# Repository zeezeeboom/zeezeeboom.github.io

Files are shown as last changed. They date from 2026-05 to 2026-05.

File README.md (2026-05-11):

# 3D Print Files

STL files for the enclosure, panel, brackets, knobs, and mounts.

## First Draft Warning

The current 3D model is a first draft. The original build required cutting and sawing parts of the print to make everything fit. Expect to trim, sand, drill, or adjust the printed parts before final assembly.

Included files:

- `AV_joystick.zip` - contains `AV_joystick.stl`; zipped because the raw STL is too large for GitHub browser upload
- `base (2).stl`
- `bottom.stl`
- `F1_knobs.stl`
- `Faceplate Riser.stl`
- `faceplate.stl`

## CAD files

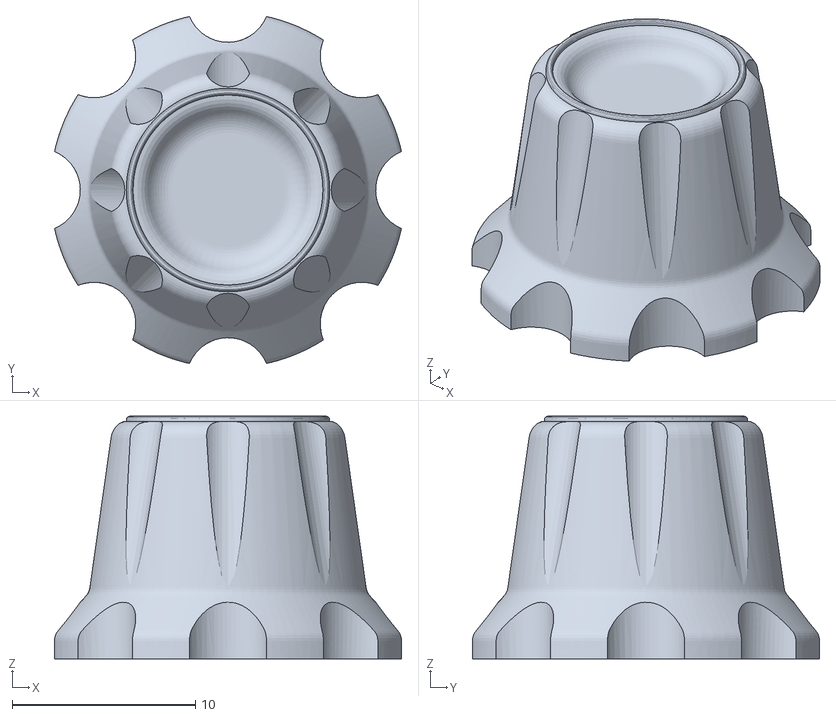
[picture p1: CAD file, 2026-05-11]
F1_knobs.stl
18.9 x 18.9 x 13.2

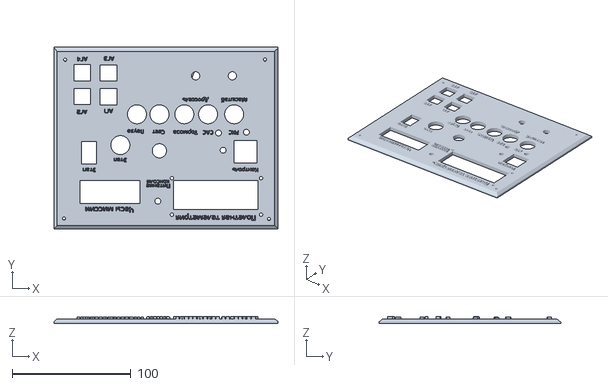
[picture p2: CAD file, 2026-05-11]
faceplate.stl
189.0 x 153.9 x 6.14

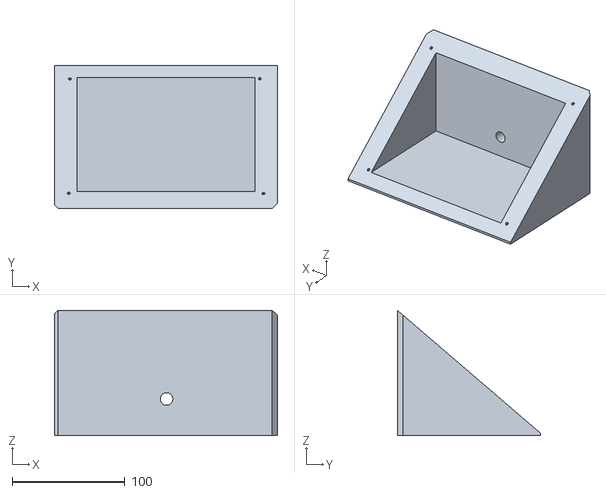
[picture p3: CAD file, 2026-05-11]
base (2).stl
198.1 x 127.2 x 111.3

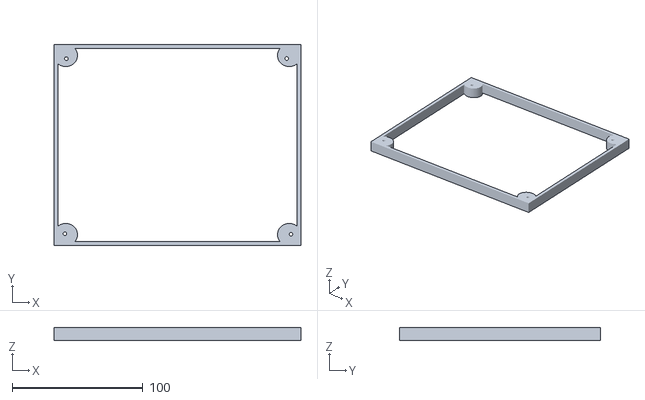
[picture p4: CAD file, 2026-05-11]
Faceplate Riser.stl
189.0 x 154.0 x 10.0

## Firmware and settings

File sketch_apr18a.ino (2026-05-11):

#include <Wire.h>
#include <LiquidCrystal_I2C.h>
#include <KerbalSimpit.h>
#include <Encoder.h>
#include <SevSeg.h>

KerbalSimpit mySimpit(Serial);
LiquidCrystal_I2C lcd(0x27, 16, 2);
SevSeg sevseg;

// Joystick
const byte PIN_VERTICAL = A0;
const byte PIN_HORIZONTAL = A1;
const byte PIN_JOYSTICK_SW = 46;

// LCD page encoder
Encoder pageEnc(2, 3);
const byte PIN_PAGE_ENC_SW = 4;

// One shared toggle switch
const byte PIN_DISPLAY_MODE_SWITCH = 5;

// LEDs
const byte PIN_SAS_LED = 6;
const byte PIN_RCS_LED = 7;
const byte PIN_ORBIT_LED = 15;
const byte PIN_SYSTEM_OFF_LED = 16;

// Main controls
const byte PIN_BRAKES = 8;
const byte PIN_LIGHTS = 9;
const byte PIN_STAGE = 10;
const byte PIN_SAS = 11;
const byte PIN_RCS = 12;
const byte PIN_GEAR = 14;

// Throttle encoder
Encoder throttleEnc(18, 19);
const byte PIN_THROTTLE_SW = 29;

// 1 digit stage display: A, B, C, D, E, F, G
const byte stageSegmentPins[] = {22, 23, 24, 25, 26, 27, 28};

// 4 digit 7 segment altitude display
byte numDigits = 4;

// Reversed from original so USSR displays in the correct order
byte digitPins[] = {30, 31, 32, 33};

byte segmentPins[] = {34, 35, 36, 37, 38, 39, 40, 41};

// Action groups
const byte agPins[] = {42, 43, 44, 45};

const int DEADZONE = 50;
const unsigned long BUTTON_DEBOUNCE_MS = 250;
const unsigned long JOYSTICK_SEND_MS = 20;
const unsigned long LCD_UPDATE_MS = 100;
const unsigned long SEV_SET_MS = 25;

const uint16_t MAX_THROTTLE = 65535;
const uint16_t MIN_THROTTLE = 0;
const uint16_t STEP_SIZE = 2184;
const long MAX_ENCODER_POS = 120;

const int totalPages = 4;

const byte digitPatterns[] = {
  0b00111111,
  0b00000110,
  0b01011011,
  0b01001111,
  0b01100110,
  0b01101101,
  0b01111101,
  0b00000111,
  0b01111111,
  0b01101111
};

// Stage countdown / display
bool isCounting = false;
bool firstStageDone = false;
int stageCount = 0;
unsigned long stageStartTime = 0;

// LCD pages
long oldPagePosition = -999;
int currentPage = 0;

// Throttle
uint16_t currentThrottle = 0;
long oldThrottlePosition = -999;

// Flight data
double vSurf = 0.0;
float altSea = 0.0;
float apoapsis = 0.0;
float periapsis = 0.0;
float burnDV = 0.0;
int32_t burnTime = 0;
float targetDist = 0.0;
float targetV = 0.0;

// 4 digit display data
long currentAltitude = 0;
bool connected = false;

// LEDs
bool reachedSpace = false;

// Timing state for stable SevSeg refresh
unsigned long lastJoystickSend = 0;
unsigned long lastJoystickToggle = 0;
unsigned long lastLcdUpdate = 0;
unsigned long lastSevSet = 0;

// Button states
bool lastAgState[4] = {HIGH, HIGH, HIGH, HIGH};
bool lastStageState = HIGH;
bool lastPageEncSwState = HIGH;
bool lastJoystickSwState = HIGH;
bool joystickRollMode = false;
bool lastSasState = HIGH;
bool lastRcsState = HIGH;
bool lastBrakesState = HIGH;
bool lastLightsState = HIGH;
bool lastGearState = HIGH;
bool lastThrottleSwState = HIGH;

bool pressed(byte pin, bool &lastState) {
  bool currentState = digitalRead(pin);
  bool didPress = currentState == LOW && lastState == HIGH;
  lastState = currentState;
  return didPress;
}

bool displayModeActive() {
  return digitalRead(PIN_DISPLAY_MODE_SWITCH) == LOW;
}

void displayStageDigit(int digit) {
  if (digit < 0 || digit > 9) {
    for (int i = 0; i < 7; i++) {
      digitalWrite(stageSegmentPins[i], LOW);
    }
    return;
  }

  byte pattern = digitPatterns[digit];

  for (int i = 0; i < 7; i++) {
    digitalWrite(stageSegmentPins[i], bitRead(pattern, i));
  }
}

void resetStageDisplay() {
  isCounting = false;
  firstStageDone = false;
  stageCount = 0;
  displayStageDigit(-1);
}

void formatDist(float dist) {
  if (dist > 1000000) {
    lcd.print(dist / 1000000, 2);
    lcd.print("Mm");
  } else if (dist > 10000) {
    lcd.print(dist / 1000, 1);
    lcd.print("km");
  } else {
    lcd.print(dist, 0);
    lcd.print("m");
  }
}

void displayAscent() {
  sevseg.refreshDisplay();
  lcd.setCursor(0, 0);
  lcd.print("SPD:");
  lcd.print(vSurf, 1);
  lcd.print("m/s    ");

  sevseg.refreshDisplay();
  lcd.setCursor(0, 1);
  lcd.print("ALT:");
  lcd.print(altSea > 10000 ? altSea / 1000 : altSea, 1);
  lcd.print(altSea > 10000 ? "km     " : "m      ");
  sevseg.refreshDisplay();
}

void displayOrbit() {
  sevseg.refreshDisplay();
  lcd.setCursor(0, 0);
  lcd.print("AP:");
  formatDist(apoapsis);
  lcd.print("        ");

  sevseg.refreshDisplay();
  lcd.setCursor(0, 1);
  lcd.print("PE:");
  formatDist(periapsis);
  lcd.print("        ");
  sevseg.refreshDisplay();
}

void displayManeuver() {
  sevseg.refreshDisplay();
  lcd.setCursor(0, 0);
  lcd.print("NODE:");
  lcd.print(burnDV, 1);
  lcd.print("dV     ");

  sevseg.refreshDisplay();
  lcd.setCursor(0, 1);
  lcd.print("TIME:");
  lcd.print(burnTime);
  lcd.print("s      ");
  sevseg.refreshDisplay();
}

void displayTarget() {
  sevseg.refreshDisplay();
  lcd.setCursor(0, 0);
  lcd.print("TGT:");
  formatDist(targetDist);
  lcd.print("        ");

  sevseg.refreshDisplay();
  lcd.setCursor(0, 1);
  lcd.print("RELV:");
  lcd.print(targetV, 1);
  lcd.print("m/s    ");
  sevseg.refreshDisplay();
}

void messageHandler(byte messageType, byte msg[], byte msgSize) {
  switch (messageType) {
    case VELOCITY_MESSAGE:
      if (msgSize == sizeof(velocityMessage)) {
        velocityMessage vData;
        memcpy(&vData, msg, sizeof(velocityMessage));
        vSurf = vData.surface;
      }
      break;

    case ALTITUDE_MESSAGE:
      if (msgSize == sizeof(altitudeMessage)) {
        altitudeMessage aData;
        memcpy(&aData, msg, sizeof(altitudeMessage));

        altSea = aData.sealevel;
        currentAltitude = (long)aData.sealevel;
        connected = true;

        if (altSea >= 70000.0) {
          reachedSpace = true;
        }

        if (altSea < 500.0) {
          reachedSpace = false;
        }

        digitalWrite(PIN_ORBIT_LED, reachedSpace ? HIGH : LOW);
      }
      break;

    case APSIDES_MESSAGE:
      if (msgSize == sizeof(apsidesMessage)) {
        apsidesMessage apData;
        memcpy(&apData, msg, sizeof(apsidesMessage));
        apoapsis = apData.apoapsis;
        periapsis = apData.periapsis;
      }
      break;

    case MANEUVER_MESSAGE:
      if (msgSize == sizeof(maneuverMessage)) {
        maneuverMessage mData;
        memcpy(&mData, msg, sizeof(maneuverMessage));
        burnDV = mData.deltaVTotal;
        burnTime = mData.timeToNextManeuver;
      }
      break;

    case TARGETINFO_MESSAGE:
      if (msgSize == sizeof(targetMessage)) {
        targetMessage tData;
        memcpy(&tData, msg, sizeof(targetMessage));
        targetDist = tData.distance;
        targetV = tData.velocity;
      }
      break;

    case ACTIONSTATUS_MESSAGE:
      {
        bool sasActive = msg[0] & 16;
        bool rcsActive = msg[0] & 8;

        digitalWrite(PIN_SAS_LED, sasActive ? HIGH : LOW);
        digitalWrite(PIN_RCS_LED, rcsActive ? HIGH : LOW);
        digitalWrite(PIN_SYSTEM_OFF_LED, (!sasActive && !rcsActive) ? HIGH : LOW);
      }
      break;
  }
}

void setup() {
  Serial.begin(115200);

  pinMode(PIN_VERTICAL, INPUT);
  pinMode(PIN_HORIZONTAL, INPUT);
  pinMode(PIN_JOYSTICK_SW, INPUT_PULLUP);

  pinMode(PIN_PAGE_ENC_SW, INPUT_PULLUP);
  pinMode(PIN_DISPLAY_MODE_SWITCH, INPUT_PULLUP);

  pinMode(PIN_STAGE, INPUT_PULLUP);
  pinMode(PIN_SAS, INPUT_PULLUP);
  pinMode(PIN_RCS, INPUT_PULLUP);
  pinMode(PIN_BRAKES, INPUT_PULLUP);
  pinMode(PIN_LIGHTS, INPUT_PULLUP);
  pinMode(PIN_GEAR, INPUT_PULLUP);
  pinMode(PIN_THROTTLE_SW, INPUT_PULLUP);

  for (int i = 0; i < 4; i++) {
    pinMode(agPins[i], INPUT_PULLUP);
  }

  for (int i = 0; i < 7; i++) {
    pinMode(stageSegmentPins[i], OUTPUT);
  }

  pinMode(PIN_SAS_LED, OUTPUT);
  pinMode(PIN_RCS_LED, OUTPUT);
  pinMode(PIN_ORBIT_LED, OUTPUT);
  pinMode(PIN_SYSTEM_OFF_LED, OUTPUT);

  displayStageDigit(-1);

  lcd.init();
  lcd.backlight();

  // COMMON_CATHODE restored; digit order stays reversed
  sevseg.begin(COMMON_CATHODE, numDigits, digitPins, segmentPins, false);
  sevseg.setBrightness(100);

  while (!mySimpit.init()) {
    sevseg.refreshDisplay();
    delay(10);
  }

  mySimpit.inboundHandler(messageHandler);

  mySimpit.registerChannel(ROTATION_MESSAGE);
  mySimpit.registerChannel(VELOCITY_MESSAGE);
  mySimpit.registerChannel(ALTITUDE_MESSAGE);
  mySimpit.registerChannel(APSIDES_MESSAGE);
  mySimpit.registerChannel(MANEUVER_MESSAGE);
  mySimpit.registerChannel(TARGETINFO_MESSAGE);
  mySimpit.registerChannel(ACTIONSTATUS_MESSAGE);

  lcd.print("PS-2 / SPUTNIK-2");
  delay(1500);
  lcd.clear();
}

void handleJoystickButton() {
  bool currentState = digitalRead(PIN_JOYSTICK_SW);

  if (currentState == LOW &&
      lastJoystickSwState == HIGH &&
      millis() - lastJoystickToggle >= BUTTON_DEBOUNCE_MS) {
    joystickRollMode = !joystickRollMode;
    lastJoystickToggle = millis();
  }

  lastJoystickSwState = currentState;
}

void handleJoystick() {
  if (millis() - lastJoystickSend < JOYSTICK_SEND_MS) return;
  lastJoystickSend = millis();

  int rawVertical = analogRead(PIN_VERTICAL);
  int rawHorizontal = analogRead(PIN_HORIZONTAL);

  int verticalVal = (abs(rawVertical - 512) < DEADZONE) ? 0 : (rawVertical - 512);
  int horizontalVal = (abs(rawHorizontal - 512) < DEADZONE) ? 0 : (rawHorizontal - 512);

  rotationMessage rotation;

  if (joystickRollMode) {
    rotation.pitch = 0;
    rotation.yaw = 0;
    rotation.roll = (int16_t)map(horizontalVal, -512, 512, -32768, 32767);
    rotation.mask = 7;
  } else {
    rotation.pitch = (int16_t)map(verticalVal, -512, 512, 32767, -32768);
    rotation.yaw = (int16_t)map(horizontalVal, -512, 512, -32768, 32767);
    rotation.roll = 0;
    rotation.mask = 7;
  }

  mySimpit.send(ROTATION_MESSAGE, rotation);
}

void handleStage() {
  if (pressed(PIN_STAGE, lastStageState)) {
    if (firstStageDone) {
      mySimpit.activateAction(STAGE_ACTION);
      stageCount++;

      if (stageCount > 9) {
        stageCount = 0;
      }

      displayStageDigit(stageCount);
    } else if (!isCounting) {
      isCounting = true;
      stageStartTime = millis();
    }
  }

  if (isCounting) {
    unsigned long elapsed = millis() - stageStartTime;
    int remaining = 5 - (elapsed / 1000);

    if (remaining >= 0) {
      displayStageDigit(remaining);
    }

    if (elapsed >= 5000) {
      mySimpit.activateAction(STAGE_ACTION);
      isCounting = false;
      firstStageDone = true;
      stageCount = 0;
      displayStageDigit(0);
    }
  }
}

void handlePageEncoderButton() {
  if (pressed(PIN_PAGE_ENC_SW, lastPageEncSwState)) {
    resetStageDisplay();
  }
}

void handleActionButtons() {
  if (pressed(PIN_SAS, lastSasState)) mySimpit.toggleAction(SAS_ACTION);
  if (pressed(PIN_RCS, lastRcsState)) mySimpit.toggleAction(RCS_ACTION);
  if (pressed(PIN_BRAKES, lastBrakesState)) mySimpit.toggleAction(BRAKES_ACTION);
  if (pressed(PIN_LIGHTS, lastLightsState)) mySimpit.toggleAction(LIGHT_ACTION);
  if (pressed(PIN_GEAR, lastGearState)) mySimpit.toggleAction(GEAR_ACTION);

  for (int i = 0; i < 4; i++) {
    bool currentButtonState = digitalRead(agPins[i]);

    if (currentButtonState == LOW && lastAgState[i] == HIGH) {
      mySimpit.toggleCAG(i + 1);
    }

    lastAgState[i] = currentButtonState;
  }
}

void handleThrottle() {
  long newPosition = throttleEnc.read();

  if ((newPosition / 4) != (oldThrottlePosition / 4)) {
    if (currentThrottle >= MAX_THROTTLE && newPosition > oldThrottlePosition) {
      throttleEnc.write(MAX_ENCODER_POS);
      oldThrottlePosition = MAX_ENCODER_POS;
      return;
    }

    if (newPosition > oldThrottlePosition) {
      currentThrottle = currentThrottle > (MAX_THROTTLE - STEP_SIZE)
        ? MAX_THROTTLE
        : currentThrottle + STEP_SIZE;
    } else {
      currentThrottle = currentThrottle < STEP_SIZE
        ? MIN_THROTTLE
        : currentThrottle - STEP_SIZE;
    }

    throttleMessage msg;
    msg.throttle = currentThrottle;
    mySimpit.send(THROTTLE_MESSAGE, msg);

    oldThrottlePosition = newPosition;
  }

  if (pressed(PIN_THROTTLE_SW, lastThrottleSwState)) {
    currentThrottle = MAX_THROTTLE;

    throttleMessage msg;
    msg.throttle = currentThrottle;
    mySimpit.send(THROTTLE_MESSAGE, msg);

    throttleEnc.write(MAX_ENCODER_POS);
    oldThrottlePosition = MAX_ENCODER_POS;
  }
}

void handleLCD() {
  if (millis() - lastLcdUpdate < LCD_UPDATE_MS) return;
  lastLcdUpdate = millis();

  if (!displayModeActive()) {
    sevseg.refreshDisplay();
    lcd.setCursor(0, 0);
    lcd.print("PS-2 / SPUTNIK-2");
    sevseg.refreshDisplay();
    lcd.setCursor(0, 1);
    lcd.print(" TELEMETRY: STBY");
    oldPagePosition = -999;
  } else {
    long newPosition = pageEnc.read() / 4;

    if (newPosition != oldPagePosition) {
      currentPage = abs(newPosition % totalPages);
      sevseg.refreshDisplay();
      lcd.clear();
      sevseg.refreshDisplay();
      oldPagePosition = newPosition;
    }

    switch (currentPage) {
      case 0: displayAscent(); break;
      case 1: displayOrbit(); break;
      case 2: displayManeuver(); break;
      case 3: displayTarget(); break;
    }
  }
}

void handleAltitudeDisplay() {
  if (millis() - lastSevSet >= SEV_SET_MS) {
    lastSevSet = millis();

    bool switchIsOn = digitalRead(PIN_DISPLAY_MODE_SWITCH) == LOW;

    if (!switchIsOn) {
      sevseg.setChars("USSR");
    } else {
      if (!connected) {
        sevseg.setChars("wait");
      } else {
        if (currentAltitude >= 10000) {
          sevseg.setNumber(currentAltitude / 10, 2);
        } else {
          sevseg.setNumber(currentAltitude);
        }
      }
    }
  }

  sevseg.refreshDisplay();
}

void loop() {
  sevseg.refreshDisplay();

  mySimpit.update();
  sevseg.refreshDisplay();

  handleStage();
  sevseg.refreshDisplay();
  handlePageEncoderButton();
  sevseg.refreshDisplay();
  handleActionButtons();
  sevseg.refreshDisplay();
  handleThrottle();
  sevseg.refreshDisplay();
  handleJoystickButton();
  sevseg.refreshDisplay();
  handleJoystick();
  sevseg.refreshDisplay();
  handleLCD();
  sevseg.refreshDisplay();
  handleAltitudeDisplay();
}
